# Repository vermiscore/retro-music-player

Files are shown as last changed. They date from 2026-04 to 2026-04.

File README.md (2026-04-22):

# 🎵 Retro Music Player

A Raspberry Pi Zero 2W-based music player with a retro aesthetic. Features a touch display showing the current track, animated landscape scenes, and a clock — all controllable via a web UI from any device on your network.

Built as a Mother's Day gift 💐

---

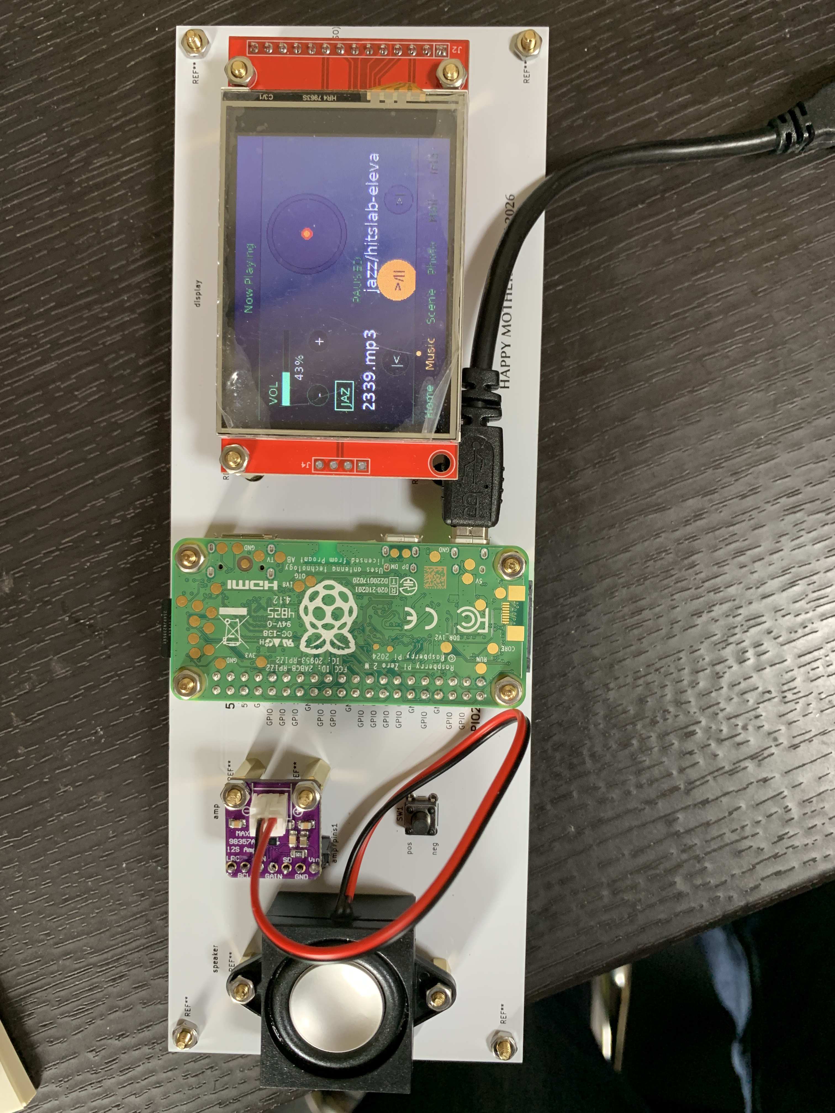
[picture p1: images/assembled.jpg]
Photo of assembled device


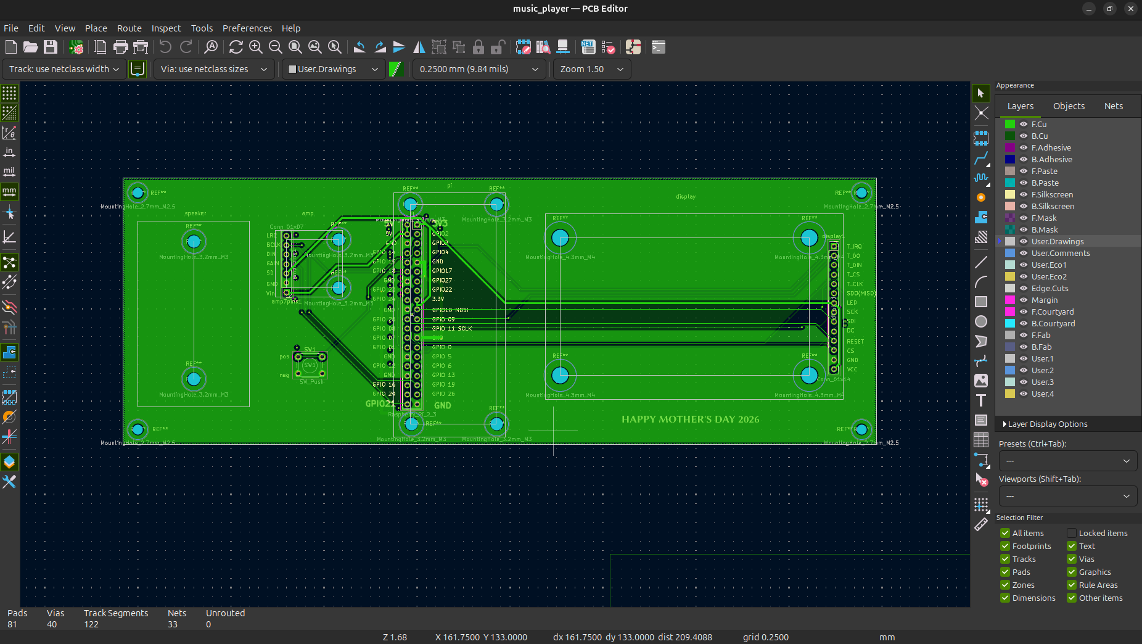
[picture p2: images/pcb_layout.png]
PCB Layout


---

## ✨ Features

| Feature | Status |
|---|---|
| OS setup & SSH access | ✅ |
| MPD music playback | ✅ |
| ILI9341 SPI touch display | ✅ |
| Auto-start on boot | ✅ |
| Tailscale remote access | ✅ |
| Web UI (Flask) | ✅ |
| Touch panel controls | ✅ |
| Multi-screen UI (Home / Music / Clock / Photo / Mail / Scene) | ✅ |
| Landscape animation (auto-launch during playback) | ✅ |
| Photo gallery & slideshow | ✅ |
| Message feature (Web UI → display) | ✅ |
| Sky color changes by time of day | ✅ |
| AirPlay (shairport-sync) | ✅ |
| MAX98357A amp wiring & audio output | ✅ |
| C++ effects processing | ❌ |

---

## 🛠 Hardware

| Component | Details |
|---|---|
| Raspberry Pi Zero 2WH | Main board |
| MAX98357A | I2S amplifier |
| ILI9341 2.4" display | SPI touch display (XPT2046 controller) |
| Speaker | 3W / 4Ω, JST-PH 2mm connector |
| microSD 32GB | Storage |
| Tactile switch | Power on/shutdown button |

---

## 🔌 Wiring

### ILI9341 Display + Touch (XPT2046)

| LCD Pin | Pi GPIO | Physical Pin | Notes |
|---|---|---|---|
| VCC | 3.3V | Pin 1 | |
| GND | GND | Pin 6 | |
| CS | GPIO8 (CE0) | Pin 24 | Display CS |
| RESET | GPIO25 | Pin 22 | |
| DC | GPIO24 | Pin 18 | |
| SDI (MOSI) | GPIO10 | Pin 19 | |
| SCK | GPIO11 | Pin 23 | |
| LED | 3.3V | Pin 17 | |
| SDO (MISO) | not connected | — | |
| **T_DO** | **GPIO9** | **Pin 21** | Touch MISO |
| T_CS | GPIO7 (CE1) | Pin 26 | Touch CS |
| T_IRQ | GPIO17 | Pin 11 | Touch interrupt |
| **T_CLK** | **GPIO11 (shared)** | **Pin 23** | Shared with SCK |
| **T_DIN** | **GPIO10 (shared)** | **Pin 19** | Shared with MOSI |

> ⚠️ T_CLK and T_DIN are branched from Pin 23 and Pin 19 respectively.

### MAX98357A Amplifier

| Amp Pin | Pi GPIO | Physical Pin |
|---|---|---|
| VDD | 5V | Pin 2 |
| GND | GND | Pin 6 |
| BCLK | GPIO18 | Pin 12 |
| LRC | GPIO19 | Pin 35 |
| DIN | GPIO21 | Pin 40 |
| SD | 3.3V | — |

### Tactile Switch (Power Button)

```
Tactile switch
├── Terminal 1 → GPIO3 (Pin 5)
└── Terminal 2 → GND  (Pin 6)
```

**Button behavior:**
- Short press (device off) → Boot
- Long press (≥ 0.5s, device on) → Shutdown

---

## 💻 Software & File Structure

```
/home/pi/
├── main.py              ← Main loop (touch & display control)
├── touch.py             ← XPT2046 touch reader
├── app.py               ← Flask Web UI server
├── display.py
├── templates/
│   └── index.html       ← Web UI HTML
├── scenes/
│   ├── common.py        ← Shared colors, fonts, nav
│   ├── home.py          ← Home screen
│   ├── music.py         ← Music screen (playback controls)
│   ├── clock.py         ← Clock screen
│   ├── mail.py          ← Mail screen (message display)
│   ├── photo.py         ← Photo gallery & slideshow
│   ├── scene_select.py  ← Landscape selection screen
│   ├── landscape.py     ← Landscape animation
│   ├── rain.py
│   └── dance.py
├── music/               ← Music files (.mp3)
├── photos/              ← Photo files
└── messages.json        ← Message history
```

---

## ⚙️ OS & Setup

- **OS**: Raspberry Pi OS Bookworm Lite 64-bit (2024-11-19)
  - ⚠️ Avoid the latest Trixie (2025-12-04) — a bug in Imager prevents SSH/Wi-Fi settings from being applied correctly.
- **Default user**: `pi`

---

## 📦 Dependencies

```bash
sudo apt install python3-pip python3-dev python3-pil fonts-dejavu mpd mpc -y
pip3 install luma.lcd flask python-mpd2 spidev numpy --break-system-packages
```

---

## 🔧 Auto-Start (systemd)

### Display service (`main.py`)

```ini
# /etc/systemd/system/display.service
[Unit]
Description=Display Service
After=network.target

[Service]
ExecStart=/usr/bin/python3 /home/pi/main.py
WorkingDirectory=/home/pi
Restart=always
User=pi

[Install]
WantedBy=multi-user.target
```

### Flask Web UI service

```ini
# /etc/systemd/system/flask.service
[Unit]
Description=Flask Web UI
After=network.target

[Service]
ExecStart=/usr/bin/python3 /home/pi/app.py
WorkingDirectory=/home/pi
Restart=always
User=pi

[Install]
WantedBy=multi-user.target
```

### Enable both services

```bash
sudo systemctl enable display flask
sudo systemctl start display flask
```

---

## 🌐 Web UI

Access the Web UI from any browser on the same network:

```
http://<raspberry-pi-ip>:5000
```

**Features:** Music playback control, file management, photo upload, message sending, system controls.

> **Tip:** If the port is busy, run:
> ```bash
> sudo kill $(sudo fuser 5000/tcp 2>/dev/null)
> sudo systemctl start flask
> ```
> Or add this alias to `~/.bashrc` for convenience:
> ```bash
> alias fixflask='sudo kill $(sudo fuser 5000/tcp 2>/dev/null); sudo systemctl start flask'
> ```

---

## 🎵 MPD Configuration

### `/etc/mpd.conf` changes

```
music_directory "/home/pi/music"
bind_to_address "any"

audio_output {
    type        "alsa"
    name        "I2S Audio"
    device      "dmixer"
    mixer_type  "software"
}
```

### Permissions

```bash
chmod 755 /home/pi
sudo chown -R mpd:audio /home/pi/music
```

### Basic playback commands

```bash
mpc ls | mpc add   # Add all tracks
mpc play           # Play
mpc next           # Next track
mpc current        # Show current track
mpc stop           # Stop
```

---

## ➕ Adding Music

**Via SCP (recommended):**
```bash
scp ~/Downloads/song.mp3 pi@<raspberry-pi-ip>:/home/pi/music/
```

**Via Web UI:**
1. Web UI → Files tab → Upload files
2. Player tab → click "Scan Library"

> Either way, press **Scan Library** after adding files.

---

## 🔊 MAX98357A Troubleshooting

### Problem: No audio output

**Symptom:** Device appears in `aplay -l` but no sound.

**Root cause:** GPIO18 (BCLK) is not set to `PCM_CLK` by the overlay automatically.

**Diagnosis:**
```bash
pinctrl get 18,19,20,21
# GPIO18 should show PCM_CLK — if it shows "output", this is the bug
```

**Fix:**

1. Edit `/boot/firmware/config.txt`:
```
dtparam=i2s=on
# dtparam=audio=on   ← comment this out (conflicts with I2S)
dtoverlay=max98357a,no-sdmode
```

2. Create a systemd service to force GPIO18 to `PCM_CLK` on boot:

```ini
# /etc/systemd/system/i2s-fix.service
[Unit]
Description=Fix GPIO18 for I2S
After=multi-user.target

[Service]
Type=oneshot
ExecStartPre=/bin/sleep 3
ExecStart=/usr/bin/pinctrl set 18 a0
RemainAfterExit=yes

[Install]
WantedBy=multi-user.target
```

```bash
sudo systemctl enable i2s-fix
sudo systemctl start i2s-fix
```

> **Note:** If the display service reconfigures GPIO18 as output, restart both services:
> ```bash
> sudo systemctl restart display && sudo systemctl restart i2s-fix
> ```

---

### Problem: Buzzing / popping noise

**Root cause:** MAX98357A pops/buzzes when the I2S clock starts or stops.

**Fix:** Use ALSA `dmix` and continuously play silence to keep the I2S clock alive.

**1. Create `/etc/asound.conf`:**
```
pcm.dmixer {
    type dmix
    ipc_key 1024
    ipc_perm 0666
    slave {
        pcm "hw:0,0"
        rate 48000
        channels 2
    }
}
pcm.!default {
    type plug
    slave.pcm "dmixer"
}
```

**2. Create `/etc/systemd/system/aplay-silence.service`:**
```ini
[Unit]
Description=Play silence to keep I2S clock alive
After=sound.target

[Service]
ExecStart=/usr/bin/aplay -D dmixer -t raw -r 48000 -c 2 -f S16_LE /dev/zero
Restart=always

[Install]
WantedBy=multi-user.target
```

```bash
sudo systemctl enable aplay-silence
sudo systemctl daemon-reload
sudo reboot
```

---

## 📻 AirPlay Setup

```bash
sudo apt install shairport-sync -y
```

That's it — `shairport-sync` auto-starts on boot.

**Usage:**
1. Open Control Center on iPhone
2. Tap the AirPlay icon
3. Select `raspberrypi`
4. Play music from any app (Apple Music, Spotify, YouTube, etc.)

---

## 🖐 Touch Calibration

```python
X_MIN, X_MAX = 251, 3735
Y_MIN, Y_MAX = 220, 3842
```

Coordinate transform in `touch.py` (X/Y swap + X invert):
```python
x = SCREEN_W - int((y_raw - Y_MIN) / (Y_MAX - Y_MIN) * SCREEN_W)
y = int((x_raw - X_MIN) / (X_MAX - X_MIN) * SCREEN_H)
```

---

## 🗒 Known Issues

- Buzzing/popping noise is mitigated by the `aplay-silence` workaround above.
- If the Web UI port 5000 is occupied by another process (e.g. shairport-sync), change the Flask port to 5001.
- `systemd-networkd-wait-online.service` can block boot for 2+ minutes — disable it if startup is slow:
  ```bash
  sudo systemctl disable systemd-networkd-wait-online.service
  ```

---

## 📐 PCB

Designed in KiCad. Files are in the [`hardware/`](hardware/) directory.

- `music_player.kicad_pcb` — PCB layout
- `music_player.kicad_sch` — Schematic
- `gerber/` — Gerber files for PCB fabrication (e.g. JLCPCB)

---

## 📄 License

MIT License

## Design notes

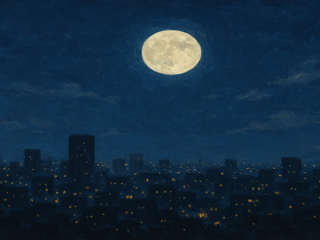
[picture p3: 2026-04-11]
scenes/night_bg.png

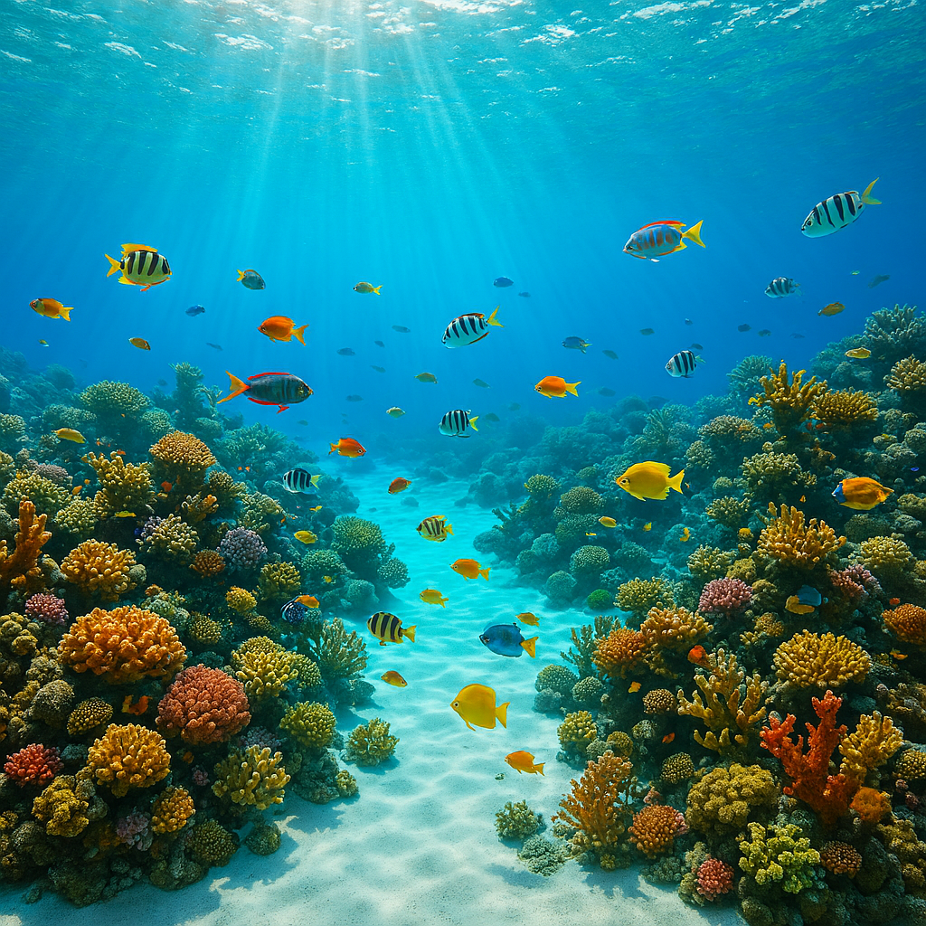
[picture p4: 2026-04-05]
scenes/underwater.png

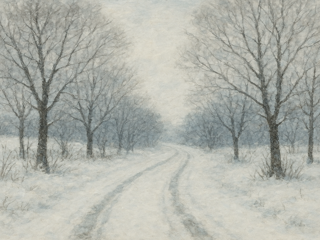
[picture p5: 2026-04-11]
scenes/snow_bg.png

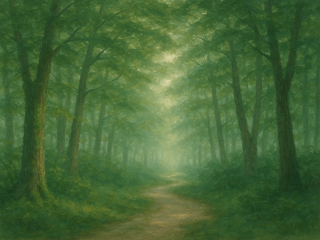
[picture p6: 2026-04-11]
scenes/forest_bg.png

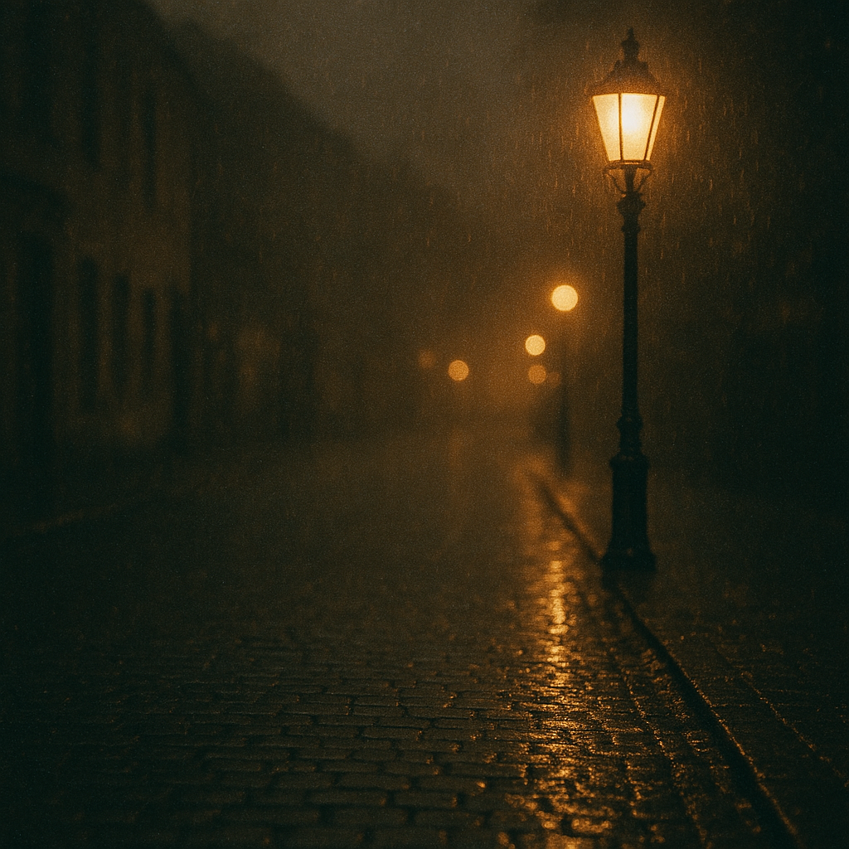
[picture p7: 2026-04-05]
scenes/rain_bg.png

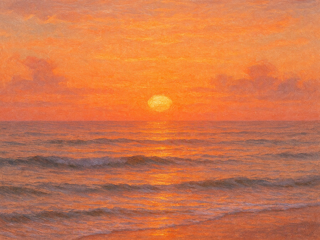
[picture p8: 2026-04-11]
scenes/ocean_bg.png

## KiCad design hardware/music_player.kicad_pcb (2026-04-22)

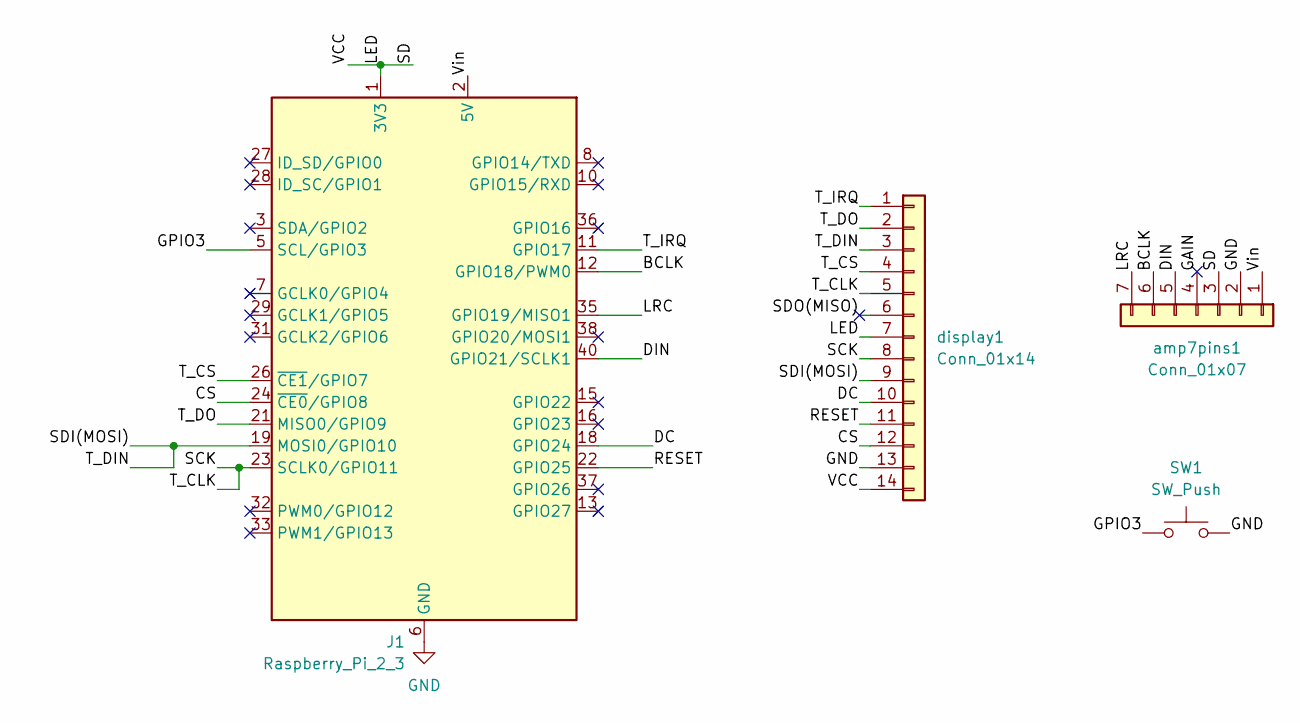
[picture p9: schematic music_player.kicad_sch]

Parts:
J1: Raspberry_Pi_2_3; PinSocket_2x20_P2.54mm_Vertical
SW1: SW_Push; SW_PUSH_6mm
amp7pins1: Conn_01x07; PinHeader_1x07_P2.54mm_Vertical
display1: Conn_01x14; PinSocket_1x14_P2.54mm_Vertical

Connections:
/BCLK: J1.12 (GPIO18/PWM0), amp7pins1.6
/CS: J1.24 (~CE0/GPIO8), display1.12
/DC: J1.18 (GPIO24), display1.10
/DIN: J1.40 (GPIO21/SCLK1), amp7pins1.5
/GAIN: amp7pins1.4
/GPIO3: J1.5 (SCL/GPIO3), SW1.1
/LED: J1.1 (3V3), J1.17 (3V3), amp7pins1.3, display1.7, display1.14
/LRC: J1.35 (GPIO19/MISO1), amp7pins1.7
/RESET: J1.22 (GPIO25), display1.11
/SCK: J1.23 (SCLK0/GPIO11), display1.5, display1.8
/SDI(MOSI): J1.19 (MOSI0/GPIO10), display1.3, display1.9
/SDO(MISO): display1.6
/T_CS: J1.26 (~CE1/GPIO7), display1.4
/T_DO: J1.21 (MISO0/GPIO9), display1.2
/T_IRQ: J1.11 (GPIO17), display1.1
/Vin: J1.2 (5V), J1.4 (5V), amp7pins1.1
GND: J1.6 (GND), J1.9 (GND), J1.14 (GND), J1.20 (GND), J1.25 (GND), J1.30 (GND), J1.34 (GND), J1.39 (GND), SW1.2, amp7pins1.2, display1.13

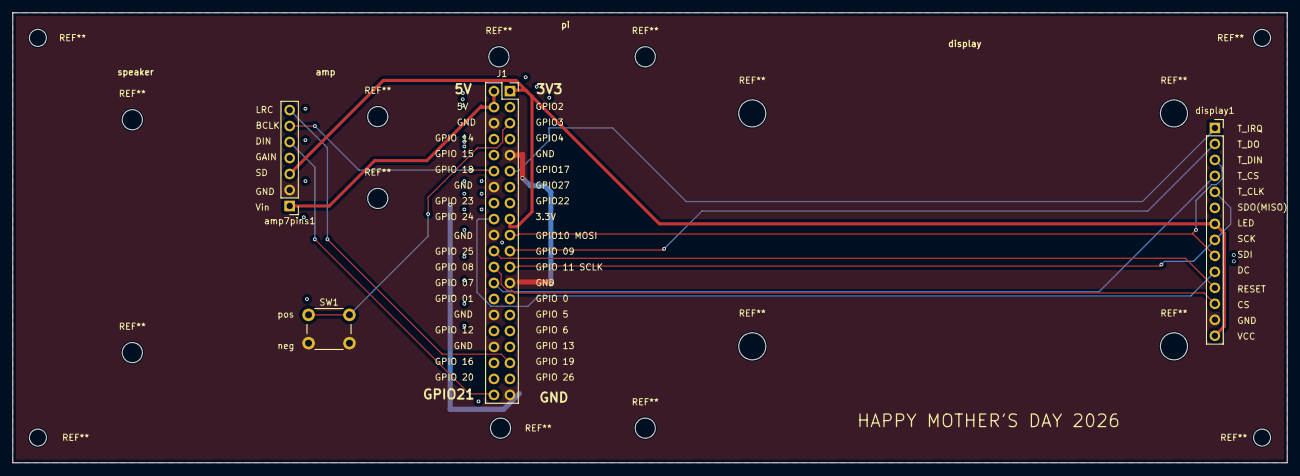
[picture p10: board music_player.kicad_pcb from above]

Board: 2 copper layers, 202.5 x 71.5 mm, 4 parts (0 on the bottom side), 15 nets.

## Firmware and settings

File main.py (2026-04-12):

from luma.lcd.device import ili9341
from luma.core.interface.serial import spi as luma_spi
from PIL import Image
import time, datetime, threading, json

import touch
from scenes.common import *
from scenes import home, music, clock, mail, photo, scene_select
_clock_speech_now = None

import importlib
import os
import subprocess
import RPi.GPIO as GPIO

# GPIO3シャットダウンボタン設定
GPIO.setmode(GPIO.BCM)
GPIO.setup(3, GPIO.IN, pull_up_down=GPIO.PUD_UP)

# デバイス初期化
serial = luma_spi(port=0, device=0, gpio_DC=24, gpio_RST=25, bus_speed_hz=16000000)
device = ili9341(serial, width=320, height=240, rotate=0)

# 状態
current_screen   = SCREEN_HOME
current_scene_id = "landscape"
was_playing      = False
idle_timer       = 0
IDLE_BACK        = 15 * 20

scroll_x     = 0
scroll_pause = 0
last_song    = ""

# 通知バナー

notification_text  = ""
notification_timer = 0
last_notified_time = "0"

# 起動時のメッセージ数を記録
try:
    with open("/home/pi/messages.json") as f:
        msgs = json.load(f)
    last_notified_count = len(msgs)
except:
    last_notified_count = 0
    

# 起動時i2s-fix
subprocess.Popen(["sudo", "systemctl", "restart", "i2s-fix"])

# タッチ排他ロック
touch_lock      = threading.Lock()
last_touch_time = 0
DEBOUNCE        = 0.4

def get_scene_module():
    try:
        return importlib.import_module(f"scenes.{current_scene_id}")
    except:
        from scenes import landscape
        return landscape

# メインループ
while True:
    now = datetime.datetime.now()
    mpd = get_mpd()

    # メッセージ通知チェック（増えた時だけ）
    try:
        with open("/home/pi/messages.json") as f:
            msgs = json.load(f)
        if len(msgs) > last_notified_count:
            notification_text = "* You got a message! *"
            notification_timer = 100
        last_notified_count = len(msgs)
    except:
        pass

    if notification_timer > 0:
        notification_timer -= 1

    # シャットダウンボタン
    if GPIO.input(3) == GPIO.LOW:
        time.sleep(0.5)
        if GPIO.input(3) == GPIO.LOW:
            subprocess.call(["sudo", "sh", "-c", "echo 0 > /sys/class/backlight/*/brightness"])
            os.system("sudo shutdown -h now")

    # タッチ処理
    pos = touch.read_touch()
    now_t = time.time()

    if pos and (now_t - last_touch_time) > DEBOUNCE:
        tx, ty = pos
        last_touch_time = now_t
        idle_timer = 0

        nav_target = hit_nav(tx, ty)
        if nav_target is not None:
            current_screen = nav_target

        elif current_screen == SCREEN_MUSIC:
            action = music.hit_button(tx, ty)
            if action:
                music.do_action(action, mpd)

        elif current_screen == SCREEN_SCENE:
            sid = scene_select.hit_scene(tx, ty)
            if sid:
                current_scene_id = sid
                current_screen   = SCREEN_LANDSCAPE

        elif current_screen == SCREEN_CLOCK:
            clock.handle_touch(tx, ty, now, mpd)
        elif current_screen == SCREEN_MAIL:
            mail.handle_touch(tx, ty)

        elif current_screen == SCREEN_PHOTO:
            photo.handle_touch(tx, ty)

    # 自動Landscape起動
    if mpd["playing"] and not was_playing:
        current_screen = SCREEN_LANDSCAPE
    was_playing = mpd["playing"]

    # スクロール更新
    if mpd["song"] != last_song:
        last_song    = mpd["song"]
        scroll_x     = 0
        scroll_pause = 0

    if text_w(mpd["song"], FONT_SMALL) > W - 50:
        if scroll_pause < 50:
            scroll_pause += 1
        else:
            scroll_x += 1.2

    # 描画
    image = Image.new("RGB", (W, H), BG)

    if current_screen == SCREEN_HOME:
        home.draw(image, now, mpd, scroll_x)

    elif current_screen == SCREEN_MUSIC:
        music.draw(image, now, mpd, scroll_x)

    elif current_screen == SCREEN_CLOCK:
        clock.draw(image, now, mpd, scroll_x)

    elif current_screen == SCREEN_MAIL:
        mail.draw(image, now, mpd, scroll_x)

    elif current_screen == SCREEN_PHOTO:
        photo.draw(image, now, mpd, scroll_x)

    elif current_screen == SCREEN_SCENE:
        scene_select.draw(image, now, mpd, current_scene_id)

    elif current_screen == SCREEN_LANDSCAPE:
        scene_mod = get_scene_module()
        if hasattr(scene_mod, "draw_frame"):
            scene_mod.draw_frame(image, now, mpd, scroll_x)
        else:
            home.draw(image, now, mpd, scroll_x)

        from PIL import ImageDraw as ID
        d = ID.Draw(image)
        d.rounded_rectangle([8, H-28, 70, H-6], radius=4, fill=BG2, outline=BORDER, width=1)
        d.text((14, H-24), "⌂ Home", font=FONT_TINY, fill=CREAM2)

    # 通知バナー描画
    if notification_timer > 0:
        from PIL import ImageDraw as ID2
        d2 = ID2.Draw(image)
        d2.rounded_rectangle([0, 0, W, 30], radius=0, fill=(40, 80, 40))
        d2.text((10, 7), notification_text, font=FONT_SMALL, fill=(200, 255, 200))

    device.display(image)
    time.sleep(0.03)

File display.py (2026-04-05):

from luma.lcd.device import ili9341
from luma.core.interface.serial import spi
from luma.core.render import canvas
from PIL import Image, ImageDraw, ImageFont
import time
import datetime
import subprocess

# ── デバイス初期化 ──────────────────────────────────────────
serial = spi(port=0, device=0, gpio_DC=24, gpio_RST=25, bus_speed_hz=16000000)
device = ili9341(serial, width=320, height=240, rotate=0)

# ── フォント ────────────────────────────────────────────────
try:
    font_huge  = ImageFont.truetype("/usr/share/fonts/truetype/dejavu/DejaVuSans-Bold.ttf", 72)
    font_large = ImageFont.truetype("/usr/share/fonts/truetype/dejavu/DejaVuSans-Bold.ttf", 48)
    font_med   = ImageFont.truetype("/usr/share/fonts/truetype/dejavu/DejaVuSans.ttf", 24)
    font_small = ImageFont.truetype("/usr/share/fonts/truetype/dejavu/DejaVuSans.ttf", 18)
    font_tiny  = ImageFont.truetype("/usr/share/fonts/truetype/dejavu/DejaVuSans.ttf", 14)
except:
    font_huge = font_large = font_med = font_small = font_tiny = ImageFont.load_default()

# ── カラーパレット（ボタニカルグリーン） ──────────────────
BG       = (28, 45, 28)       # ダークグリーン背景
BG2      = (45, 65, 45)       # カード背景（明るめ）
CREAM    = (245, 238, 220)    # クリームテキスト（より明るく）
CREAM2   = (200, 190, 165)    # サブテキスト
SAGE     = (150, 200, 150)    # セージグリーン（鮮やかに）
ACCENT   = (220, 170, 120)    # テラコッタ/アンバー（明るく）
ACCENT2  = (200, 130, 85)     # ダークテラコッタ
MUTED    = (130, 170, 130)    # ミュートグリーン（明るく）
BORDER   = (80, 110, 80)      # ボーダー（見やすく）
BLACK    = (0, 0, 0)

# ── 画面定数 ────────────────────────────────────────────────
W, H = 320, 240
NAV_H = 36          # ボトムナビの高さ
SCREEN_HOME  = 0
SCREEN_MUSIC = 1
SCREEN_CLOCK = 2

# ── 状態 ────────────────────────────────────────────────────
current_screen = SCREEN_HOME
scroll_x       = 0
scroll_pause   = 0
last_song      = ""

# ── MPD情報取得 ──────────────────────────────────────────────
def get_mpd_info():
    try:
        status = subprocess.run(["mpc", "status"], capture_output=True, text=True, timeout=1).stdout
        current = subprocess.run(["mpc", "current"], capture_output=True, text=True, timeout=1).stdout.strip()
        playing = "[playing]" in status
        song = current if current else "No song"
        return {"playing": playing, "song": song}
    except:
        return {"playing": False, "song": "No song"}

# ── テキスト幅計測 ───────────────────────────────────────────
def text_width(text, font):
    dummy = Image.new("RGB", (1, 1))
    d = ImageDraw.Draw(dummy)
    bbox = d.textbbox((0, 0), text, font=font)
    return bbox[2] - bbox[0]

def text_center_x(text, font, area_w, offset_x=0):
    w = text_width(text, font)
    return offset_x + (area_w - w) // 2

# ── 植物デコレーション描画 ────────────────────────────────────
def draw_botanical(draw, x, y, scale=1.0, alpha_color=BORDER):
    """シンプルな植物モチーフを描く"""
    s = scale
    # 茎
    draw.line([(x, y), (x, int(y - 40*s))], fill=alpha_color, width=1)
    # 左の葉
    draw.ellipse([int(x-18*s), int(y-35*s), int(x-2*s), int(y-22*s)], outline=alpha_color, width=1)
    # 右の葉
    draw.ellipse([int(x+2*s), int(y-28*s), int(x+18*s), int(y-15*s)], outline=alpha_color, width=1)
    # 上の葉
    draw.ellipse([int(x-8*s), int(y-52*s), int(x+8*s), int(y-38*s)], outline=alpha_color, width=1)
    # 小さい花
    draw.ellipse([int(x-5*s), int(y-58*s), int(x+5*s), int(y-48*s)], fill=ACCENT2, outline=ACCENT)

# ── ボトムナビ描画 ──────────────────────────────────────────
def draw_nav(draw, active):
    y0 = H - NAV_H
    draw.rectangle([0, y0, W, H], fill=BG2)
    draw.line([(0, y0), (W, y0)], fill=BORDER, width=1)

    tabs = [("Home", SCREEN_HOME), ("Music", SCREEN_MUSIC), ("Clock", SCREEN_CLOCK)]
    tab_w = W // len(tabs)

    for i, (label, screen_id) in enumerate(tabs):
        tx = i * tab_w + tab_w // 2
        ty = y0 + NAV_H // 2 - 7
        color = ACCENT if active == screen_id else MUTED
        bbox = draw.textbbox((0, 0), label, font=font_tiny)
        lw = bbox[2] - bbox[0]
        draw.text((tx - lw//2, ty), label, font=font_tiny, fill=color)
        if active == screen_id:
            dot_x = tx
            draw.ellipse([dot_x-2, y0+3, dot_x+2, y0+7], fill=ACCENT)

# ── スクロールテキスト描画 ───────────────────────────────────
def draw_scroll_text(image, text, font, x, y, max_w, color, scroll_offset):
    tw = text_width(text, font)
    if tw <= max_w:
        draw = ImageDraw.Draw(image)
        draw.text((x, y), text, font=font, fill=color)
        return

    gap = 50
    loop_w = tw + gap
    off = Image.new("RGB", (loop_w * 2, 30), BG)
    od = ImageDraw.Draw(off)
    od.text((0, 0), text, font=font, fill=color)
    od.text((loop_w, 0), text, font=font, fill=color)
    crop_x = int(scroll_offset) % loop_w
    cropped = off.crop((crop_x, 0, crop_x + max_w, 30))
    image.paste(cropped, (x, y))

# ── HOME画面 ────────────────────────────────────────────────
def draw_home(image, now, mpd):
    draw = ImageDraw.Draw(image)
    content_h = H - NAV_H

    # 背景
    draw.rectangle([0, 0, W, H], fill=BG)

    # 装飾（左・右）
    draw_botanical(draw, 18, 120, scale=0.7, alpha_color=BORDER)
    draw_botanical(draw, W-18, 120, scale=0.6, alpha_color=BORDER)

    # 時刻（大きく中央）
    time_str = now.strftime("%H:%M")
    tx = text_center_x(time_str, font_large, W)
    draw.text((tx, 20), time_str, font=font_large, fill=CREAM)

    # 日付
    date_str = now.strftime("%Y. %m. %d")
    dx = text_center_x(date_str, font_small, W)
    draw.text((dx, 78), date_str, font=font_small, fill=CREAM2)

    # 曜日バッジ
    day_str = now.strftime("%a").upper()
    dw = text_width(day_str, font_tiny)
    bx = (W - dw - 12) // 2
    draw.rounded_rectangle([bx, 100, bx + dw + 12, 118], radius=4, fill=ACCENT2)
    draw.text((bx + 6, 101), day_str, font=font_tiny, fill=CREAM)

    # 区切り線（装飾付き）
    lx = 40
    draw.line([(lx, 130), (W - lx, 130)], fill=BORDER, width=1)
    draw.ellipse([W//2 - 3, 127, W//2 + 3, 133], fill=ACCENT2)

    # 再生状態アイコン
    state_icon = "▶" if mpd["playing"] else "⏸"
    state_color = SAGE if mpd["playing"] else MUTED
    draw.text((14, 148), state_icon, font=font_tiny, fill=state_color)

    # 曲名スクロール
    draw_scroll_text(image, mpd["song"], font_small,
                     32, 145, W - 44, CREAM2, scroll_x)

    draw_nav(draw, SCREEN_HOME)
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

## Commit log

2026-04-08 update app.py and index.html - add scan library fix
    [app.py]
2026-04-08 add genre selection with scroll, fix i2s on startup
    [main.py]
2026-04-08 genre selection, i2s fix, scan library fix
    [app.py]
2026-04-12 Fix mail notification, update dance bg, update scene descriptions
    [main.py]
2026-04-22 Add README, hardware files, and photos
    [music_player.kicad_pcb, music_player.kicad_sch]
2026-04-22 Add PCB layout image to README
